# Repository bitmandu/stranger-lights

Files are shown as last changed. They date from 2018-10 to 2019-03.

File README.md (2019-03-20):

Stranger Lights
===============

This is my attempt to recreate the
[Christmas light, message wall from Stranger Things][stranger-things-tweet].
This is a popular project on the Interwebs, but is usually done using
an Arduino.

This project features:

- A bare bones ATmega328 AVR (no Arduino ecosystem)
- Command-line scripts to send tweets to the AVR over serial UART
- Random flashes — to warn you when the Demogorgon is nearby

This [video shows Stranger Lights in action][youtube].

Getting Started
---------------

An AVR-GCC Makefile is provided to compile the flash the source code.

    $ make
    $ make flash

Serial messages are read over the serial port and displayed.

### Displaying Messages with upsidedown.py

The script `bin/upsidedown.py` sends serial messages to display.

Without any command-line arguments, upsidedown.py sends a random
message like "run."

    $ ./upsidedown.py

To display your own message, just add it to the command-line.

    $ ./upsidedown.py stranger lights

The special message "~" flashes the LEDs — warning that the Demogorgon
is nearby.

    $ ./upsidedown.py ~

### Displaying Tweets

The script `bin/poll` uses [Twurl][twurl] to periodically retrieve and
display tweets containing a hashtag.

    $ ./poll

Documentation
-------------

More information on the hardware and software is in the
[documentation][docs].

Help / Issues
-------------

Please report all bugs and feature requests using the
[Issue Tracker][issues].

License
-------

[MIT](LICENSE), *except* for [Danny Havenith's ws2811 library][ws2811]
which is licensed under the [Boost Software License 1.0][boost].

[boost]: https://github.com/DannyHavenith/ws2811/blob/master/LICENSE_1_0.txt
[docs]: https://bitmandu.com/stranger-lights/latest/index.html
[issues]: https://github.com/bitmandu/stranger-lights/issues
[stranger-things-tweet]: https://twitter.com/stranger_things/status/898307224979742720
[twurl]: https://github.com/twitter/twurl
[ws2811]: https://github.com/DannyHavenith/ws2811
[youtube]: https://www.youtube.com/watch?v=xbL81dse8vs

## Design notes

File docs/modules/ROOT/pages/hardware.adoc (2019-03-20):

= Connecting the Hardware

The hardware setup is straightforward. There is only one output pin to
the LED strip to connect from PB1 (pin 15, defined in pins.h).

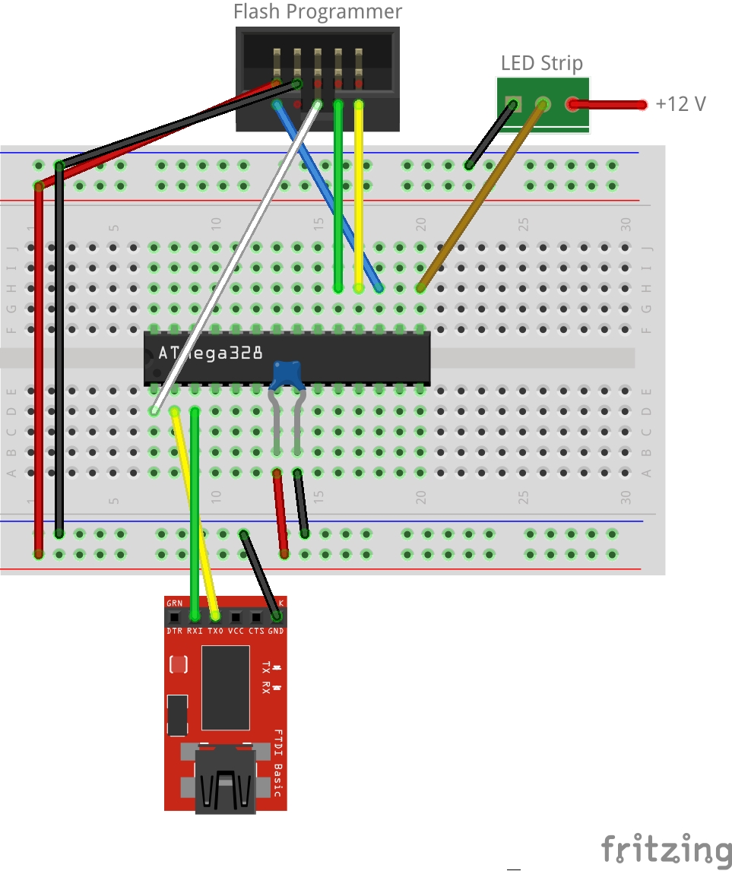
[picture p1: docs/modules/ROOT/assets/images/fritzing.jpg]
Breadboard visualized with Fritzing


IMPORTANT: Make sure to connect the ground wires from the LEDs and AVR
together. Otherwise the digital output from the AVR will be floating,
and your lights will flicker randomly.

Here is what it looks like on my breadboard.

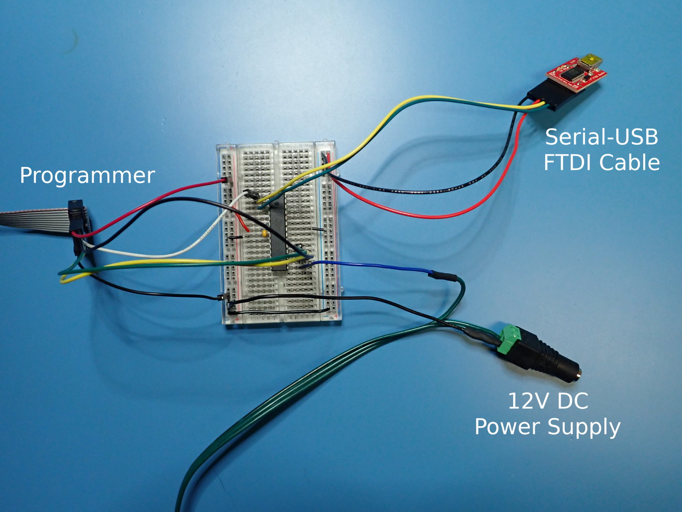
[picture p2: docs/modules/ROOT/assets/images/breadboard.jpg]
Breadboard in real-life


== LED Connection

The LED strip has three wires for the data signal, ground, and 12 V.
The power rails (12 V and ground) are connected to the AC/DC power
supply. The ground wire and data wire need to be routed back to the
AVR.

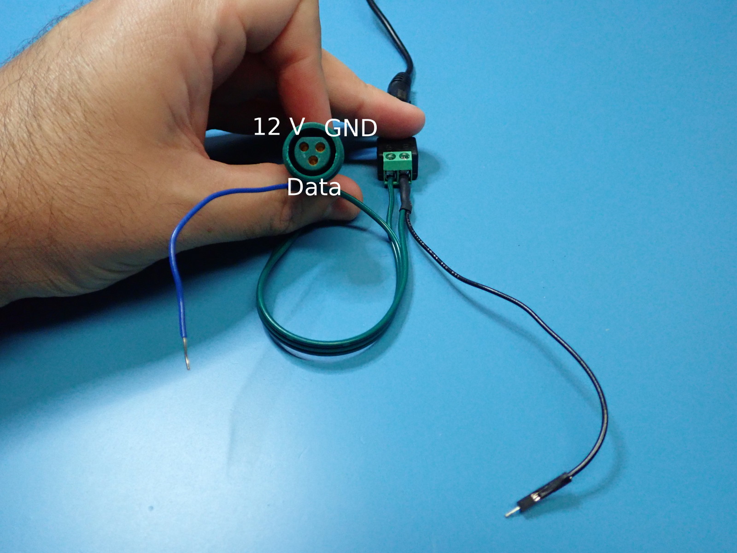
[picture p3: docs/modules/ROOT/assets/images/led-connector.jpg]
LED Connector


== AVR Power

I used my programmer to power the AVR. But once you flash the AVR, the
programmer can be removed and replaced with any 5 V power supply.

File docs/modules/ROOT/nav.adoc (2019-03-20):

- xref:index.adoc[Introduction]
- xref:materials.adoc[Materials]
- xref:hardware.adoc[Connecting the Hardware]
- xref:clock.adoc[Changing the ATmega328 Clock Speed to 8 MHz]
- xref:software.adoc[Flashing the Software]
- xref:upsidedown.adoc[Sending Messages with upsidedown.py]
- xref:twitter.adoc[Displaying Tweets]
- xref:help.adoc[Help / Issues]
- xref:license.adoc[License]

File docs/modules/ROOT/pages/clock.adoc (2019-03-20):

= Changing the ATmega328 Clock Speed to 8 MHz
:ws2811: https://github.com/DannyHavenith/ws2811
:datasheet: http://ww1.microchip.com/downloads/en/devicedoc/atmel-42735-8-bit-avr-microcontroller-atmega328-328p_datasheet.pdf

By default, the ATmega328 runs at 1 MHz. Because the bit-banging
performed by {ws2811}[Danny Havenith's ws2811 library] is timing
senitive, the AVR needs to run at a clock speed of 8 MHz.

== Step 1: Check the clock speed

The clock speed is controlled by the low fuse byte (LFUSE). Its value
can be found with avrdude.

[source, shell]
----
$ avrdude -c usbasp -p atmega328p -v

avrdude: Version 6.3, compiled on Feb  7 2018 at 03:33:11
         Copyright (c) 2000-2005 Brian Dean, http://www.bdmicro.com/
         Copyright (c) 2007-2014 Joerg Wunsch

...

avrdude: AVR device initialized and ready to accept instructions

Reading | ################################################## | 100% 0.00s

avrdude: Device signature = 0x1e950f (probably m328p)
avrdude: safemode: hfuse reads as D9
avrdude: safemode: efuse reads as FF

avrdude: safemode: hfuse reads as D9
avrdude: safemode: efuse reads as FF
avrdude: safemode: Fuses OK (E:FF, H:D9, L:62) <1>

avrdude done.  Thank you.
----
<1> `L:62` is the low fuse byte. (In hexidecimal, 0x62 = 0b01100010.)

If your chip reports `L:62`, its clock is running at 1 MHz and you
need to perform the next step.

.More on the low fuse byte (LFUSE)
****

The bits `CKDIV8` and `CKSEL` of LFUSE control the clock speed of the
ATmega238. (See pages 349-350 of the {datasheet}[datasheet].)

.Default LFUSE
[%header,cols=8]
|===
| CKDIV8 | CKOUT | SUT1 | SUT0 | CKSEL3 | CKSEL2 | CKSEL1 | CKSEL0
|      0 |     1 |    1 |    0 |      0 |      0 |      1 |      0
|===

The default value of LFUSE = 0b01100010 = 0x62, where the components
are:

CKDIV8::
Divide clock by 8

CKOUT::
Clock output

SUT::
Select start-up time

CKSEL::
Select clock source

Although `CKSEL` = 0b0010 corresponds to 8 MHz, because `CKDIV` is
programmed the clock speed is divided by 8 -- which results in the
default 1 MHz clock speed from the factory.

NOTE: In AVR lingo, fuses that are read as logical zero (0) are
"programmed."

To set the clock speed at 8 MHz, all that is needed is to leave
`CKDIV8` unprogrammed (1) so the `CLKPS` bits will be reset to 0000.

.LFUSE for an 8 MHz clock
[%header,cols=8]
|===
| CKDIV8 | CKOUT | SUT1 | SUT0 | CKSEL3 | CKSEL2 | CKSEL1 | CKSEL0
|      1 |     1 |    1 |    0 |      0 |      0 |      1 |      0
|===

This sets the clock division factor to 1, and the ATmega328 will run
at 8 MHz. Because 0b11100010 = 0xe2, we want to set LFUSE = 0xe2.
****

== Step 2: Change the clock speed using avrdude

Use avrdude to set LFUSE = 0xe2 to run the ATmega328 at 8 MHz.

[source, shell]
----
$ avrdude -c usbasp -p atmega328p -v -U lfuse:w:0xe2:m

avrdude: Version 6.3, compiled on Jul 12 2018 at 21:00:17
         Copyright (c) 2000-2005 Brian Dean, http://www.bdmicro.com/
         Copyright (c) 2007-2014 Joerg Wunsch

...

avrdude: AVR device initialized and ready to accept instructions

Reading | ################################################## | 100% 0.00s

avrdude: Device signature = 0x1e950f (probably m328p)
avrdude: safemode: hfuse reads as D9
avrdude: safemode: efuse reads as FF
avrdude: reading input file "0xe2"
avrdude: writing lfuse (1 bytes):

Writing | ################################################## | 100% 0.01s

avrdude: 1 bytes of lfuse written
avrdude: verifying lfuse memory against 0xe2:
avrdude: load data lfuse data from input file 0xe2:
avrdude: input file 0xe2 contains 1 bytes
avrdude: reading on-chip lfuse data:

Reading | ################################################## | 100% 0.00s

avrdude: verifying ...
avrdude: 1 bytes of lfuse verified

avrdude: safemode: hfuse reads as D9
avrdude: safemode: efuse reads as FF
avrdude: safemode: Fuses OK (E:FF, H:D9, L:E2)

avrdude done.  Thank you.
----

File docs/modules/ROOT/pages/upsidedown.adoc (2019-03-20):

= Sending Messages with upsidedown.py
:screen: https://www.gnu.org/software/screen/manual/screen.html
:miniterm: https://pyserial.readthedocs.io/en/latest/tools.html#module-serial.tools.miniterm

The Python script `bin/upsidedown.py` sends serial messages from the
command-line.

Any string received by the UART interface of the AVR is displayed.
(Assuming, you know, everything is working.) You can use whatever
serial terminal you prefer to send messages — the Linux command
{screen}[screen] and Python's pySerial {miniterm}[miniterm console]
are two options.

.Determine your serial port
****

Although upsidedown.py tries to determine your serial port (COM port),
if you have a lot of serial devices attached to your computer it may
be wrong. To list the available serial devices on your computer use
the `-l` flag.

[source, shell]
----
$ ./upsidedown.py -l
Device                                  Description
----------------------------------------------------------------------
/dev/ttyUSB0                            FT232R USB UART
----

On Linux, my serial device is `/dev/ttyUSB0`. If the default serial
port isn't working, use the `-d` flag to provide an alternative, e.g.,
`-d /dev/ttyUSB0`.

****

== Send a random message

Without any other command-line arguments, upsidedown.py will send a
random message like "run."

[source, shell]
----
$ ./upsidedown.py
----

== Send a custom message

To display your own message, just add it to the command-line.

[source, shell]
----
$ ./upsidedown.py stranger lights
----

== Flash the LEDs

The special message "~" flashes the LEDs to warn you that the
Demogorgon is nearby.

[source, shell]
----
$ ./upsidedown.py ~
----

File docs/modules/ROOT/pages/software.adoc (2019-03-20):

= Flashing the software
:avrdude: https://www.nongnu.org/avrdude/user-manual/avrdude_12.html

== Step 1: Configuration

There are a few files to edit before flashing the code to the AVR.

=== `src/ledstrip.h`

Change `NLED` to the number of LEDs for your strip.

[source, c]
----
#define NLED 50
----

=== `src/ledstrip.c`

The variable `MAP` defines which LED corresponds to each letter. For
example, `MAP[0]` is the LED index for letter "A," and `MAP[25]` is
the LED index for "Z." The LEDs in the strip are numbered from 0 to
`NLED - 1`.

In my setup, the last LED in the 50 LED strip (LED 49) is above the
letter "A," so my `MAP` is set as follows.

[source, c]
----
static const uint8_t MAP[26] = {
    49, 48, 47, 46, 45, 44, 43, 42,
    32, 33, 34, 35, 36, 37, 38, 39, 40,
    30, 29, 28, 27, 26, 25, 24, 23, 22};
----

In addition, the variable `COLOR` defines the color for each LED. In
my setup, I only use the last 28 LEDs so I set `COLOR` as follows.

[source, c]
----
static const rgb COLOR[NLED] = {
    BLACK, BLACK, BLACK, BLACK, BLACK,
    BLACK, BLACK, BLACK, BLACK, BLACK,
    BLACK, BLACK, BLACK, BLACK, BLACK,
    BLACK, BLACK, BLACK, BLACK, BLACK,
    BLACK, BLACK, GREEN, BLUE, RED,
    BLUE, YELLOW, LAVENDER, GREEN, PURPLE,
    BLUE, RED, YELLOW, LAVENDER, GREEN,
    PURPLE, BLUE, RED, YELLOW, LAVENDER,
    GREEN, PURPLE, BLUE, RED, YELLOW,
    LAVENDER, GREEN, PURPLE, BLUE, RED};
----

NOTE: `rgb.h` defines the colors APRICOT, AQUA, BLACK, BLUE, BROWN,
CYAN. FUCHSIA, GRAY, GREEN, LAVENDER, LIME, MAGENTA, MAROON, MINT,
NAVY, OLIVE, ORANGE, PINK, PURPLE, RED, SILVER, TEAL, WHITE, and
YELLOW.

=== `src/pins.h`

If you connect your LED strip to a different pin, you will also have
to update `pins.h`.

[source, c]
----
#define WS2811_PORT PORTB
#define DDR DDRB
#define PIN PB1
----

=== `src/Makefile`

You may need to change the `PROGRAMMER` line in `src/Makefile` to the
{avrdude}[AVRDUDE name] for your programmer.

[source, Makefile]
----
PROGRAMMER = usbasp
----

== Step 2: Compile the code

Compile with the AVR-GCC compiler using `make`.

[source, shell]
----
$ make
avr-gcc -g -Wall -Wpedantic -Os -DF_CPU=8000000UL -DBAUD=9600UL -mmcu=atmega328p -c -o stranger-lights.o stranger-lights.c
avr-gcc -g -Wall -Wpedantic -Os -DF_CPU=8000000UL -DBAUD=9600UL -mmcu=atmega328p -c -o ledstrip.o ledstrip.c
avr-gcc -g -Wall -Wpedantic -Os -DF_CPU=8000000UL -DBAUD=9600UL -mmcu=atmega328p -c -o usart.o usart.c
avr-gcc -Wl,-Map,.map -mmcu=atmega328p -o stranger-lights.elf stranger-lights.o ledstrip.o usart.o
----

== Step 3: Flash the AVR

Flash the AVR with avrdude using `make flash`.

[source, shell]
----
$ make flash
avr-objcopy -j .text -j .data -O ihex stranger-lights.elf stranger-lights.hex
avrdude -c usbasp -p atmega328p -U flash:w:stranger-lights.hex

avrdude: warning: cannot set sck period. please check for usbasp firmware update.
avrdude: AVR device initialized and ready to accept instructions

Reading | ################################################## | 100% 0.00s

avrdude: Device signature = 0x1e950f (probably m328p)
avrdude: NOTE: "flash" memory has been specified, an erase cycle will be performed
         To disable this feature, specify the -D option.
avrdude: erasing chip
avrdude: warning: cannot set sck period. please check for usbasp firmware update.
avrdude: reading input file "stranger-lights.hex"
avrdude: input file stranger-lights.hex auto detected as Intel Hex
avrdude: writing flash (3650 bytes):

Writing | ################################################## | 100% 1.14s

avrdude: 3650 bytes of flash written
avrdude: verifying flash memory against stranger-lights.hex:
avrdude: load data flash data from input file stranger-lights.hex:
avrdude: input file stranger-lights.hex auto detected as Intel Hex
avrdude: input file stranger-lights.hex contains 3650 bytes
avrdude: reading on-chip flash data:

Reading | ################################################## | 100% 0.95s

avrdude: verifying ...
avrdude: 3650 bytes of flash verified

avrdude: safemode: Fuses OK (E:FF, H:D9, L:E2)

avrdude done.  Thank you.
----

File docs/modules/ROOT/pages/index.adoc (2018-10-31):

= Introduction
:twitter-status: https://twitter.com/stranger_things/status/898307224979742720

This is my attempt to recreate the {twitter-status}[Christmas light,
message wall from Stranger Things]. This is a popular project on the
Interwebs, but is usually done using an Arduino.

video::xbL81dse8vs[youtube, width=640, height=480]

This project features:

* [x] A bare bones ATmega328 AVR (no Arduino ecosystem)
* [x] Command-line scripts to send tweets to the AVR over serial UART
* [x] Random flashes -- to warn you when the Demogorgon is nearby

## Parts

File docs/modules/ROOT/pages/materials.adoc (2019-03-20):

= Materials
:avr: https://www.mouser.com/ProductDetail/Microchip-Technology-Atmel/ATMEGA328-PU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
:lights: https://www.aliexpress.com/item/50nodes-addressable-RGB-C9-DC12V-WS2811-LED-Christmas-pixel-string-light-6inches-15cm-wire-spacing-all/32463619267.html
:power-supply: https://www.amazon.com/gp/product/B01AZLA9XQ/
:letters-pdf: https://www.witchesofhalloween.com.au/content/Stranger%20Things%20-%20Wall%20Letters.pdf
:letters-font: https://www.dafont.com/kg-life-is-messy.font
:led-control-chips: http://www.doityourselfchristmas.com/wiki/index.php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

* Electronics
** [x] {avr}[ATMega328-PU]
** [x] {lights}[LED Christmas Lights (WS2811, 12V)]
** [x] {power-supply}[12V Power supply]
** [x] FTDI Serial-USB Cable
** [x] Flash Programmer
* Craft Supplies
** [x] Floral wallpaper, shelf liner, or fabric
** [x] Safety pins (to hang the lights)
** [x] Paint for the letters -- or print letters using
   {letters-pdf}[this template] or the {letters-font}[KG Life is Messy Font]

// another source for "Stranger Things Wall Letters.pdf" (account required)
// https://www.scribd.com/document/345729391/Stranger-Things-Wall-Letters-pdf

IMPORTANT: To use my code, you'll need a WS2811-based LED strip. There
are several LED ICs commonly used with similar names, like WS2811,
WS2812 and WS2812b, so double-check. To learn more about the different
ICs being used in LED pixel strips, see {led-control-chips}[Different
Styles of Pixels].

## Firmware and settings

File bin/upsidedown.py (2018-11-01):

#!/usr/bin/env python3
"""Send serial messages to AVR from the Upside Down."""

import argparse
import json
import random
import re
import serial
import serial.tools.list_ports as list_ports
import sys
import time

BAUD = 9600  # serial port baud rate

# random messages selected from:
MESSAGES = ["barb", "boo", "halloween", "help", "redrum", "run", "trick or treat"]

NTRUNC = 32

def clean(tweet):
    """Clean tweet of special characters, hash tags, user names, etc."""

    words = []
    for w in re.split(r"\s+", tweet):
        if w[:4] == "http" or w[0] in ["@", "#"]:
            continue

        words.append(w.strip().lower())

    message = re.sub(r"[^a-z ]", "", " ".join(words))
    message = re.sub(r"\s+", " ", message)

    return message.strip()

def comport():
    """Default serial device."""

    try:
        port = list_ports.comports()[0].device
    except IndexError:
        port = None

    return port

def parse(results, userfile):
    """Parse Twitter search results from twurl."""

    since_id = 0
    messages = []

    for tweet in results["statuses"]:
        if tweet["id"] > since_id:
            since_id = tweet["id"]

        messages.append(clean(tweet["text"]))

        if userfile:
            screen_name = tweet["user"]["screen_name"]
            userfile.write("https://twitter.com/{}\n".format(screen_name))

    return messages, since_id

def ports():
    """Display a list of available serial ports."""

    labels = ("Device", "Description")
    header = "{0:40}{1:30}".format(*labels)

    print(header)
    print("-"*len(header))
    for port in list_ports.comports():
        print("{0.device:40}{0.description:30}".format(port))

def send(port, message):
    """Send message to serial port."""

    message = message[:NTRUNC]
    delay = 2*len(message)  # delay (in sec) to wait for message to display

    print("send: '{}' ({} s)".format(message, delay))
    port.write("{}\r\n".format(message).encode("utf-8"))
    time.sleep(delay)

if __name__ == "__main__":
    p = argparse.ArgumentParser(prog="upsidedown.py", description=__doc__)
    p.add_argument("-b", "--baud", dest="baud", type=int, default=9600,
                   help="Baud rate")
    p.add_argument("-d", "--device", dest="device", type=str,
                   default=comport(), help="Serial port device")
    p.add_argument("-i", "--id", dest="idfile", type=str,
                   help="Filename to store latest tweet ID")
    p.add_argument("-l", "--list", dest="list", action="store_true",
                   help="List available serial port devices and exit")
    p.add_argument("-t", "--twitter", dest="twitter", action="store_true",
                   help="Parse tweets from Twitter API")
    p.add_argument("-u", dest="userfile", type=str,
                   help="Filename to store Twitter user names")
    p.add_argument(dest="message", nargs="*", type=str,
                   help="Message to display")

    args = p.parse_args()

    if args.list:
        ports()
        sys.exit(0)
    elif args.twitter:
        results = json.load(sys.stdin)
        userfile = open(args.userfile, "a") if args.userfile else None
        messages, since_id = parse(results, userfile)

        if args.idfile and since_id > 0:
            with open(args.idfile, "w") as fp:
                fp.write("{}".format(since_id))
    elif args.message:
        messages = [re.sub(r"[^~a-z ]", "", " ".join(args.message))]
    else:
        messages = [random.choice(MESSAGES)]

    with serial.Serial(args.device, args.baud, timeout=5) as port:
        if not messages:
            r = random.random()
            if r < 0.6:
                print("flash")
                port.write("~\r\n".encode("utf-8"))
            else:
                send(port, random.choice(MESSAGES))
        else:
            for msg in messages:
                send(port, msg)

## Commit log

2018-10-25 Use pySerial library to send messages over UART
2018-10-28 Add Fritzing breadboard
    [stranger-lights.fzz]
2018-10-31 Use default serial device
2018-10-31 Explain how to flash the LEDs
2018-11-01 Fail gracefully if no serial port is found
    [upsidedown.py]
